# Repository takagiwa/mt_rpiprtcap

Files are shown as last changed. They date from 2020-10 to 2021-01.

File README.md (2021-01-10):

# mt_rpiprtcap

Capture print data via parallel port on PC and some measurement equipments.

Main purpose is for taking hardcopy on elder measurement equipments that don't have USB or modern hardcopy device.

The PCB design file for KiCAD is in "board" directory.

The software code depends on pigpiod is in "software_rpi" directory.

you can build software as following (comes from pigpio)

gcc -Wall -pthread -o prt prt.cpp -lpigpiod_if2 -lrt

I have tested on Raspbian GNU/Linux 10 (buster), gcc 8.3.0, pigpio 78 (get_pigpio_version reported) and Raspberry Pi 4B 2GB.

The software still have some huge bugs.

* failed to capture first byte
* sometime failed to capture data (3 or 4 characters in 10MB).
* too slow (almost 1KB/sec)

There are no interpreters that convert from parallel port data to picture yet.

How to use

connect all devices.

power-on all devices.

start software_rpi/prt executable

start print on PC or equipment

when it seems ended, Ctrl-C on prt executable

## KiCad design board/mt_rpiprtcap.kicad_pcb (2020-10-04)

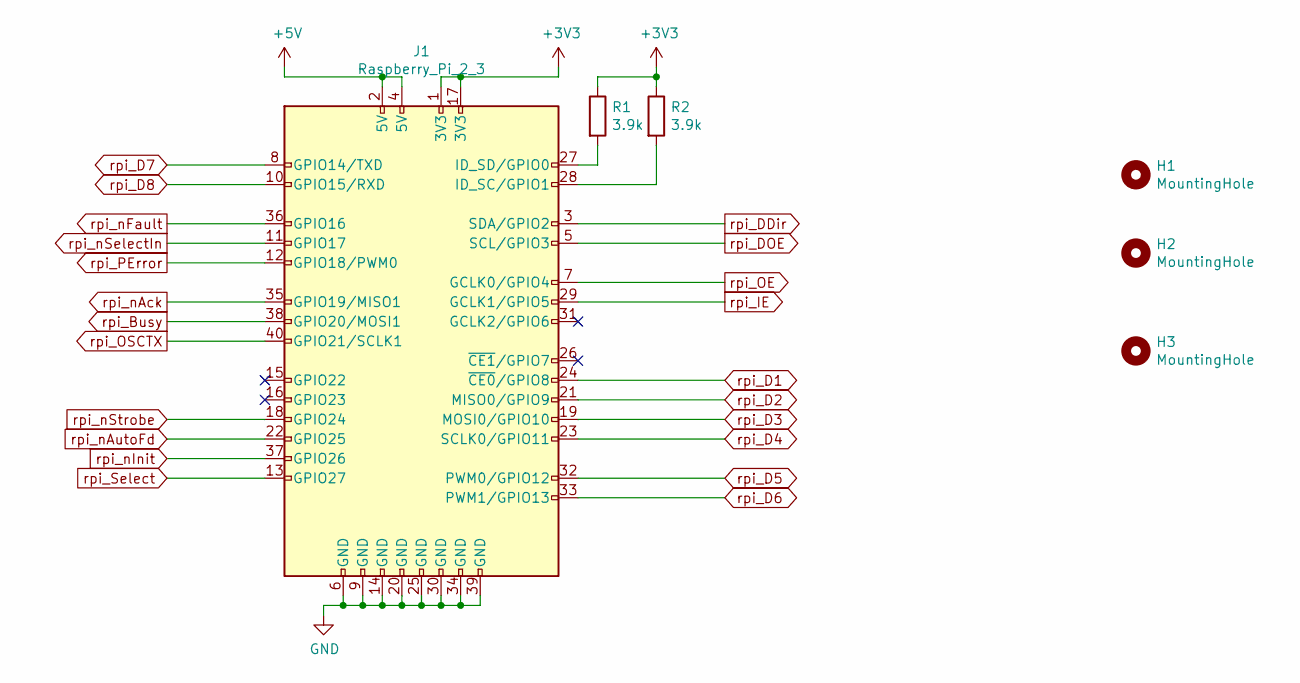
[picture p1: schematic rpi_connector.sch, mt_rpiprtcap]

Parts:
H1, H2, H3: MountingHole; MountingHole_2.7mm_M2.5
J1: Raspberry_Pi_2_3; Pin_Header_Straight_2x20_Pitch2.54mm
R1, R2: 3.9k; R_0805_HandSoldering

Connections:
+3V3: J1.1 (3V3), J1.17 (3V3), R1.1, R2.1; also elsewhere on the board
+5V: J1.2 (5V), J1.4 (5V); also elsewhere on the board
GND: J1.6 (GND), J1.9 (GND), J1.14 (GND), J1.20 (GND), J1.25 (GND), J1.30 (GND), J1.34 (GND), J1.39 (GND); also elsewhere on the board
unnamed: J1.27 (ID_SD/GPIO0), R1.2
unnamed: J1.28 (ID_SC/GPIO1), R2.2
rpi_Busy: J1.38 (GPIO20/MOSI1); also elsewhere on the board
rpi_D1: J1.24 (~CE0~/GPIO8); also elsewhere on the board
rpi_D2: J1.21 (MISO0/GPIO9); also elsewhere on the board
rpi_D3: J1.19 (MOSI0/GPIO10); also elsewhere on the board
rpi_D4: J1.23 (SCLK0/GPIO11); also elsewhere on the board
rpi_D5: J1.32 (PWM0/GPIO12); also elsewhere on the board
rpi_D6: J1.33 (PWM1/GPIO13); also elsewhere on the board
rpi_D7: J1.8 (GPIO14/TXD); also elsewhere on the board
rpi_D8: J1.10 (GPIO15/RXD); also elsewhere on the board
rpi_DDir: J1.3 (SDA/GPIO2); also elsewhere on the board
rpi_DOE: J1.5 (SCL/GPIO3); also elsewhere on the board
rpi_IE: J1.29 (GCLK1/GPIO5); also elsewhere on the board
rpi_OE: J1.7 (GCLK0/GPIO4); also elsewhere on the board
rpi_OSCTX: J1.40 (GPIO21/SCLK1); also elsewhere on the board
rpi_PError: J1.12 (GPIO18/PWM0); also elsewhere on the board
rpi_Select: J1.13 (GPIO27); also elsewhere on the board
rpi_nAck: J1.35 (GPIO19/MISO1); also elsewhere on the board
rpi_nAutoFd: J1.22 (GPIO25); also elsewhere on the board
rpi_nFault: J1.36 (GPIO16); also elsewhere on the board
rpi_nInit: J1.37 (GPIO26); also elsewhere on the board
rpi_nSelectIn: J1.11 (GPIO17); also elsewhere on the board
rpi_nStrobe: J1.18 (GPIO24); also elsewhere on the board

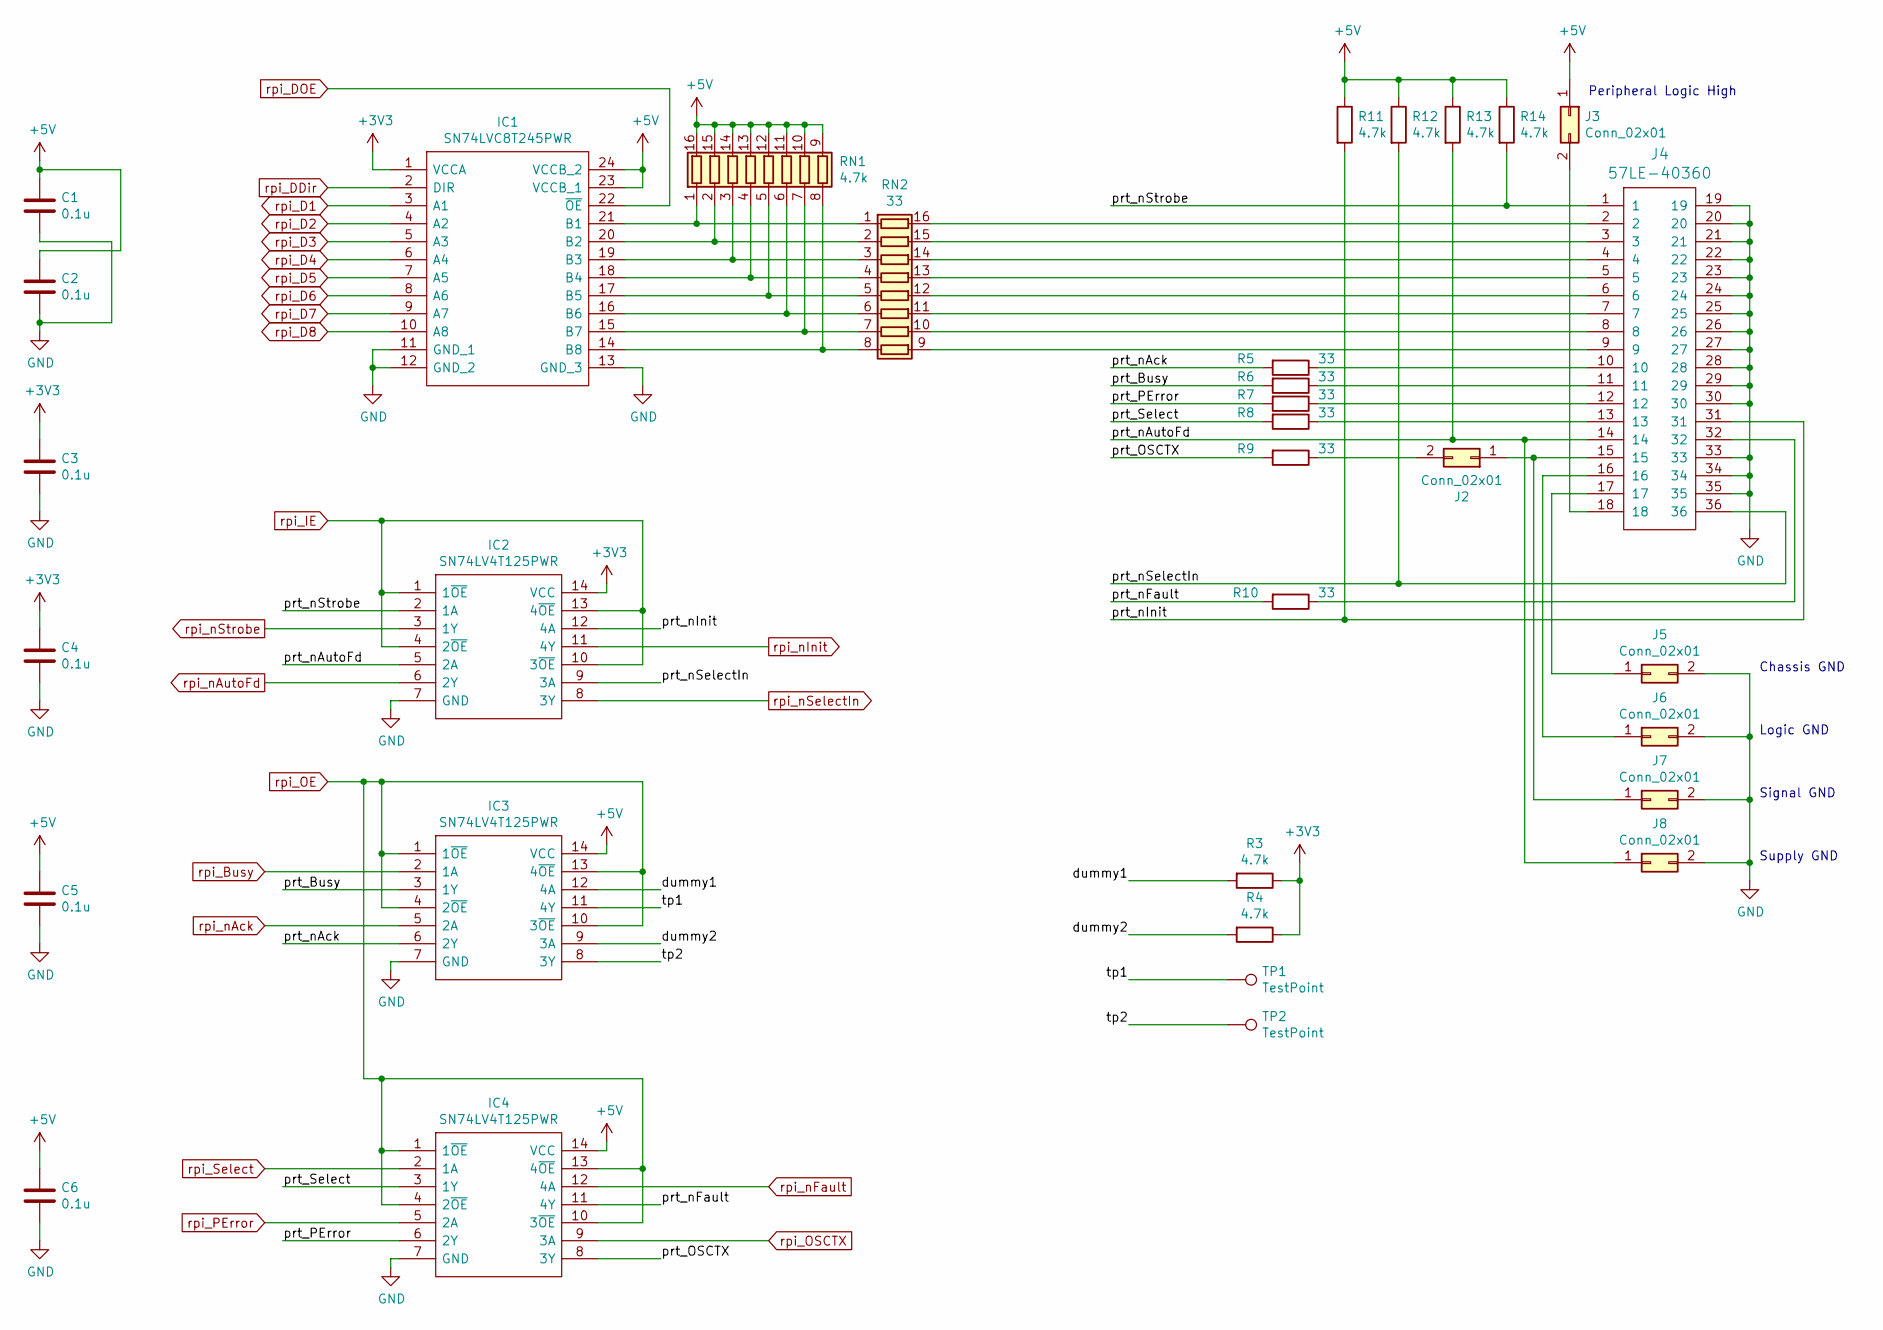
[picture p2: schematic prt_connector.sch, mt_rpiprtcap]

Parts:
C1, C2, C3, C4, C5, C6: 0.1u; C_0805_HandSoldering
IC1: SN74LVC8T245PWR; SOP65P640X120-24N; Mouser Part Number 595-SN74LVC8T245PWR
IC2, IC3, IC4: SN74LV4T125PWR; SOP65P640X120-14N; Mouser Part Number 595-SN74LV4T125PWR
J2, J3, J5, J6, J7, J8: Conn_02x01; Pin_Header_Straight_2x01_Pitch2.54mm
J4: 57LE-40360
R3, R4, R11, R12, R13, R14: 4.7k; R_0805_HandSoldering
R5, R6, R7, R8, R9, R10: 33; R_0805_HandSoldering
RN1: 4.7k; R_Array_Convex_8x0602
RN2: 33; R_Array_Convex_8x0602
TP1, TP2: TestPoint; Measurement_Point_Round-SMD-Pad_Small

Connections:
+3V3: C3.1, C4.1, IC1.1 (VCCA), IC2.14 (VCC), R3.1, R4.1; also elsewhere on the board
+5V: C1.1, C2.1, C5.1, C6.1, IC1.23 (VCCB_1), IC1.24 (VCCB_2), IC3.14 (VCC), IC4.14 (VCC), J3.1, R11.1, R12.1, R13.1, R14.1, RN1.9 (R8.2), RN1.10 (R7.2), RN1.11 (R6.2), RN1.12 (R5.2), RN1.13 (R4.2), RN1.14 (R3.2), RN1.15 (R2.2), RN1.16 (R1.2); also elsewhere on the board
/prt_connector/dummy1: IC3.12 (4A), R3.2
/prt_connector/dummy2: IC3.9 (3A), R4.2
/prt_connector/prt_Busy: IC3.3 (1Y), R6.2
/prt_connector/prt_OSCTX: IC4.8 (3Y), R9.2
/prt_connector/prt_PError: IC4.6 (2Y), R7.2
/prt_connector/prt_Select: IC4.3 (1Y), R8.2
/prt_connector/prt_nAck: IC3.6 (2Y), R5.2
/prt_connector/prt_nAutoFd: IC2.5 (2A), J4.14, J8.1, R13.2
/prt_connector/prt_nFault: IC4.11 (4Y), R10.2
/prt_connector/prt_nInit: IC2.12 (4A), J4.31, R11.2
/prt_connector/prt_nSelectIn: IC2.9 (3A), J4.36, R12.2
/prt_connector/prt_nStrobe: IC2.2 (1A), J4.1, R14.2
/prt_connector/tp1: IC3.11 (4Y), TP1.1
/prt_connector/tp2: IC3.8 (3Y), TP2.1
GND: C1.2, C2.2, C3.2, C4.2, C5.2, C6.2, IC1.11 (GND_1), IC1.12 (GND_2), IC1.13 (GND_3), IC2.7 (GND), IC3.7 (GND), IC4.7 (GND), J4.19, J4.20, J4.21, J4.22, J4.23, J4.24, J4.25, J4.26, J4.27, J4.28, J4.29, J4.30, J4.33, J4.34, J4.35, J5.2, J6.2, J7.2, J8.2; also elsewhere on the board
unnamed: IC1.14 (B8), RN1.8 (R8.1), RN2.8 (R8.1)
unnamed: IC1.15 (B7), RN1.7 (R7.1), RN2.7 (R7.1)
unnamed: IC1.16 (B6), RN1.6 (R6.1), RN2.6 (R6.1)
unnamed: IC1.17 (B5), RN1.5 (R5.1), RN2.5 (R5.1)
unnamed: IC1.18 (B4), RN1.4 (R4.1), RN2.4 (R4.1)
unnamed: IC1.19 (B3), RN1.3 (R3.1), RN2.3 (R3.1)
unnamed: IC1.20 (B2), RN1.2 (R2.1), RN2.2 (R2.1)
unnamed: IC1.21 (B1), RN1.1 (R1.1), RN2.1 (R1.1)
unnamed: J2.1, J4.15, J7.1
unnamed: J2.2, R9.1
unnamed: J3.2, J4.18
unnamed: J4.2, RN2.16 (R1.2)
unnamed: J4.3, RN2.15 (R2.2)
unnamed: J4.4, RN2.14 (R3.2)
unnamed: J4.5, RN2.13 (R4.2)
unnamed: J4.6, RN2.12 (R5.2)
unnamed: J4.7, RN2.11 (R6.2)
unnamed: J4.8, RN2.10 (R7.2)
unnamed: J4.9, RN2.9 (R8.2)
unnamed: J4.10, R5.1
unnamed: J4.11, R6.1
unnamed: J4.12, R7.1
unnamed: J4.13, R8.1
unnamed: J4.16, J6.1
unnamed: J4.17, J5.1
unnamed: J4.32, R10.1
rpi_Busy: IC3.2 (1A); also elsewhere on the board
rpi_D1: IC1.3 (A1); also elsewhere on the board
rpi_D2: IC1.4 (A2); also elsewhere on the board
rpi_D3: IC1.5 (A3); also elsewhere on the board
rpi_D4: IC1.6 (A4); also elsewhere on the board
rpi_D5: IC1.7 (A5); also elsewhere on the board
rpi_D6: IC1.8 (A6); also elsewhere on the board
rpi_D7: IC1.9 (A7); also elsewhere on the board
rpi_D8: IC1.10 (A8); also elsewhere on the board
rpi_DDir: IC1.2 (DIR); also elsewhere on the board
rpi_DOE: IC1.22 (~OE); also elsewhere on the board
rpi_IE: IC2.1 (1~OE), IC2.4 (2~OE), IC2.10 (3~OE), IC2.13 (4~OE); also elsewhere on the board
rpi_OE: IC3.1 (1~OE), IC3.4 (2~OE), IC3.10 (3~OE), IC3.13 (4~OE), IC4.1 (1~OE), IC4.4 (2~OE), IC4.10 (3~OE), IC4.13 (4~OE); also elsewhere on the board
rpi_OSCTX: IC4.9 (3A); also elsewhere on the board
rpi_PError: IC4.5 (2A); also elsewhere on the board
rpi_Select: IC4.2 (1A); also elsewhere on the board
rpi_nAck: IC3.5 (2A); also elsewhere on the board
rpi_nAutoFd: IC2.6 (2Y); also elsewhere on the board
rpi_nFault: IC4.12 (4A); also elsewhere on the board
rpi_nInit: IC2.11 (4Y); also elsewhere on the board
rpi_nSelectIn: IC2.8 (3Y); also elsewhere on the board
rpi_nStrobe: IC2.3 (1Y); also elsewhere on the board

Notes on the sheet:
Peripheral Logic High
Chassis GND
Logic GND
Signal GND
Supply GND

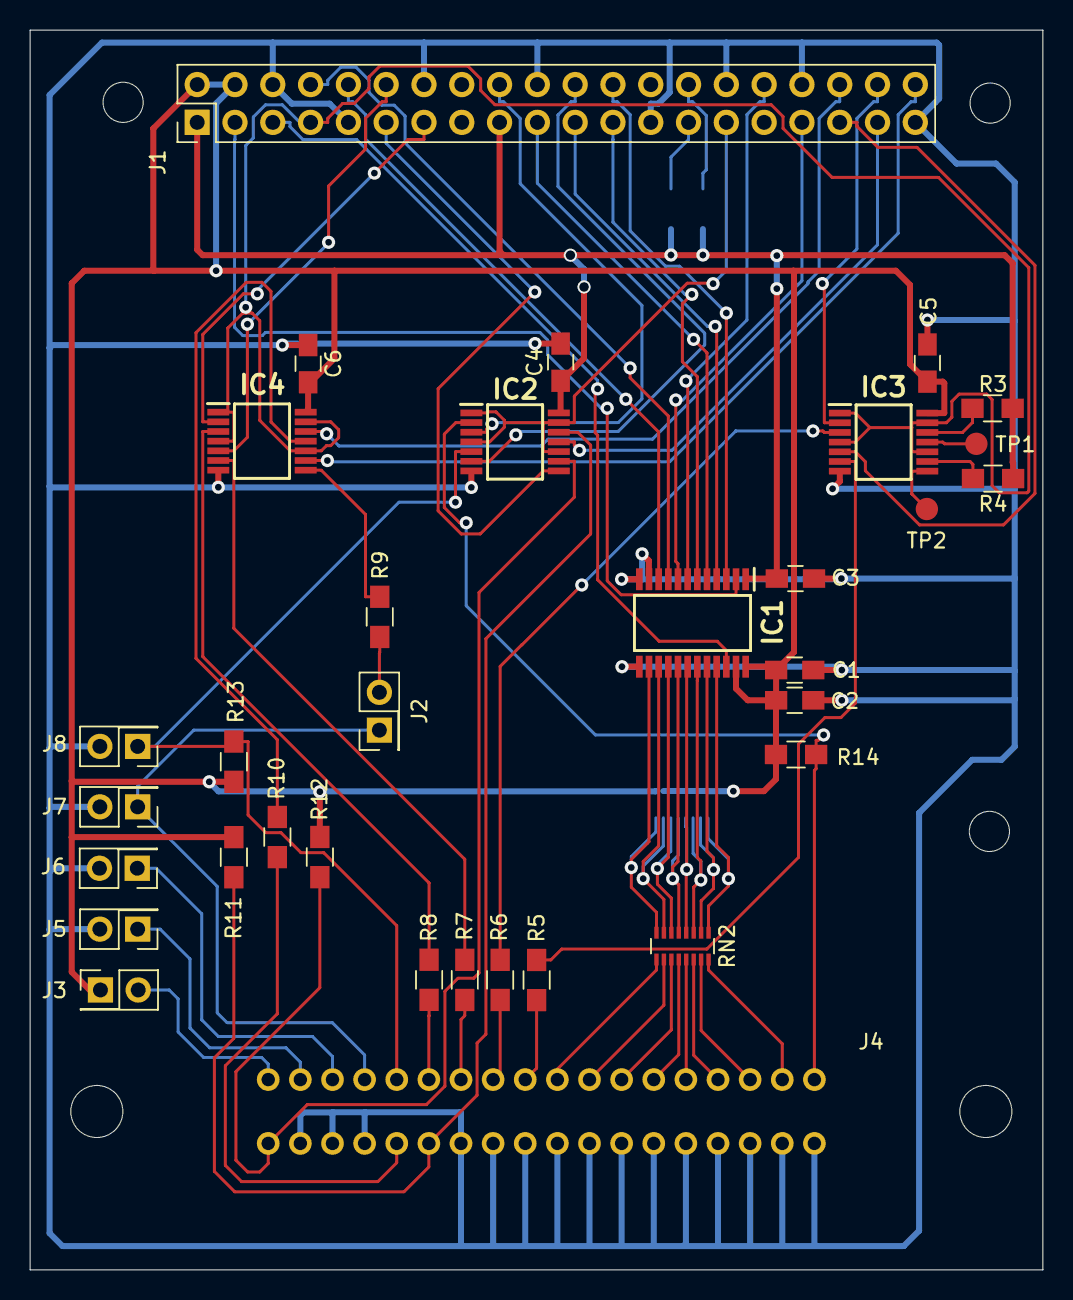
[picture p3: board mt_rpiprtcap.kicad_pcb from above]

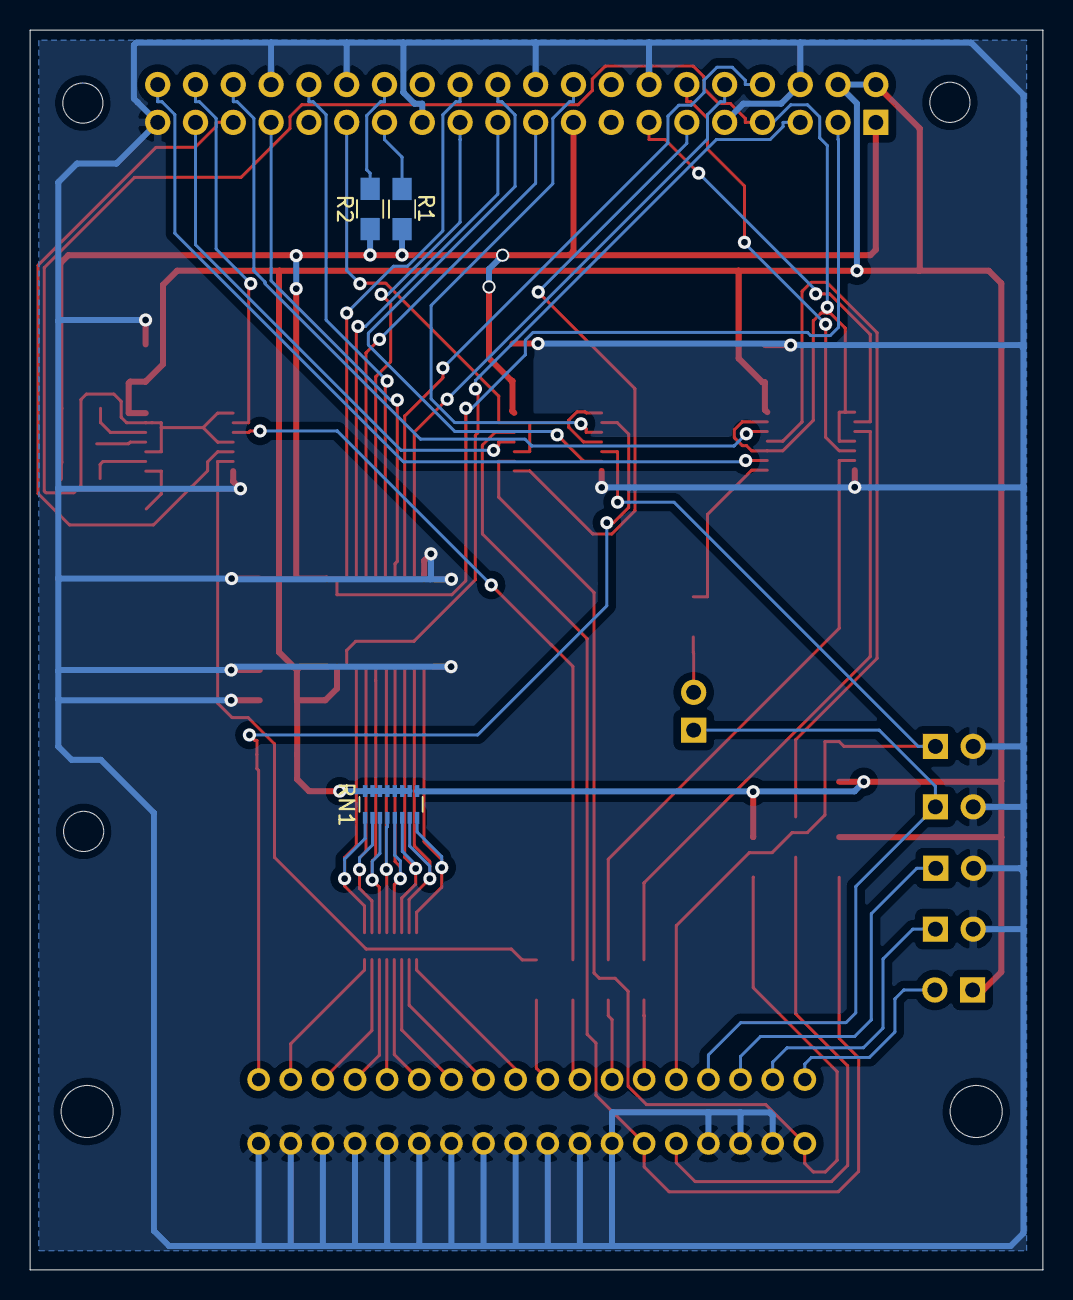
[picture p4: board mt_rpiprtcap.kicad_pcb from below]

Board: 2 copper layers, 68.1 x 83.3 mm, 39 parts (3 on the bottom side), 67 nets.

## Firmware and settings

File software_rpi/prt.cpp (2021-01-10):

#include <stdio.h>
#include <stdlib.h>
#include <string.h>
#include <time.h>
#include <signal.h>
#include <pigpiod_if2.h>

enum PRT_PORTS {
  PRT_O_DDir = 2,
  PRT_O_DOE,
  PRT_O_OE,
  PRT_O_IE,
  PRT_I_D1 = 8,
  PRT_I_D2,
  PRT_I_D3,
  PRT_I_D4,
  PRT_I_D5,
  PRT_I_D6,
  PRT_I_D7,
  PRT_I_D8,
  PRT_O_nFault,
  PRT_O_nSelectIn,
  PRT_O_PError,
  PRT_O_nAck,
  PRT_O_Busy,
  PRT_O_OSCTX,
  PRT_I_nStrobe = 24,
  PRT_I_nAutoFd,
  PRT_I_nInit,
  PRT_I_Select
};

/* Handle Ctrl-C */
/* https://qiita.com/supaiku2452/items/10772cbd2706dede06b9 */
void abrt_handler(int sig, siginfo_t *info, void *ctx);
volatile sig_atomic_t eflag = 0;

int my_set_mode(int pi, unsigned int gpio, unsigned int mode)
{
  int ret;
  ret = set_mode(pi, gpio, mode);
  if (ret < 0) {
    printf("[ERROR] set_mode error for %d: %s\n", gpio, pigpio_error(ret));
    return -1;
  }
  return 0;
}

int my_gpio_write(int pi, unsigned int gpio, unsigned level)
{
  int ret;
  ret = gpio_write(pi, gpio, level);
  if (ret < 0) {
    printf("[ERROR] gpio_write error for %d: %s\n", gpio, pigpio_error(ret));
    return -1;
  }
  return 0;
}

int main(void)
{
  unsigned int v;
  int pi;
  uint32_t r;
  int ret;
  unsigned int rd;
  int i, j, b, prev_b;
  FILE *fp;

  /* handle Ctrl-C */
  struct sigaction sa_sigabrt;
  memset(&sa_sigabrt, 0, sizeof(sa_sigabrt));
  sa_sigabrt.sa_sigaction = abrt_handler;
  sa_sigabrt.sa_flags = SA_SIGINFO;
  if ( sigaction(SIGINT, &sa_sigabrt, NULL) < 0 ) {
    exit(1);
  }

  v = pigpiod_if_version();
  printf("[INFO] pigpiod_if2 version: %d\n", v);

  pi = pigpio_start(0, 0);
  if (pi < 0) {
    printf("[ERROR] pigpio_start() failed: %s\n", pigpio_error(pi));
    return -1;
  }
  printf("[INFO] pi: %d\n", pi);

  r = get_pigpio_version(pi);
  printf("[INFO] pigpio version: %d\n", r);

  r = get_hardware_revision(pi);
  printf("[INFO] hardware revision: %d\n", r);

  /* set initial output data */
  ret = 0;
  ret += my_gpio_write(pi, PRT_O_DDir, 0); /* input */
  ret += my_gpio_write(pi, PRT_O_DOE, 0); /* active */
  ret += my_gpio_write(pi, PRT_O_OE, 0); /* active */
  ret += my_gpio_write(pi, PRT_O_IE, 0); /* active */
  ret += my_gpio_write(pi, PRT_O_nFault, 1); /* low when error */
  ret += my_gpio_write(pi, PRT_O_nSelectIn, 1); /* high when selected and ready */
  ret += my_gpio_write(pi, PRT_O_PError, 0); /* high to "empty" */
  ret += my_gpio_write(pi, PRT_O_nAck, 1); /* low when ack */
  ret += my_gpio_write(pi, PRT_O_Busy, 0); /* high when not ready to receive */
  ret += my_gpio_write(pi, PRT_O_OSCTX, 0); /* should not used */
  if (ret != 0) {
    printf("[ERROR] initial gpio_write error.\n");
    pigpio_stop(pi);
    return -1;
  }

  /* direction setup */
  ret = 0;
  if (0) ret += my_set_mode(pi, 0, PI_INPUT);  /* pullup */
  if (0) ret += my_set_mode(pi, 1, PI_INPUT);  /* pullup */
  ret += my_set_mode(pi, 2, PI_OUTPUT); /* DDir */
  ret += my_set_mode(pi, 3, PI_OUTPUT); /* DOE */
  ret += my_set_mode(pi, 4, PI_OUTPUT); /* OE */
  ret += my_set_mode(pi, 5, PI_OUTPUT); /* IE */
  ret += my_set_mode(pi, 6, PI_INPUT);  /* N.C. */
  ret += my_set_mode(pi, 7, PI_INPUT);  /* N.C. */
  ret += my_set_mode(pi, 8, PI_INPUT);  /* D1 */
  ret += my_set_mode(pi, 9, PI_INPUT);  /* D2 */
  ret += my_set_mode(pi, 10, PI_INPUT); /* D3 */
  ret += my_set_mode(pi, 11, PI_INPUT); /* D4 */
  ret += my_set_mode(pi, 12, PI_INPUT); /* D5 */
  ret += my_set_mode(pi, 13, PI_INPUT); /* D6 */
  ret += my_set_mode(pi, 14, PI_INPUT); /* D7 */
  ret += my_set_mode(pi, 15, PI_INPUT); /* D8 */
  ret += my_set_mode(pi, 16, PI_OUTPUT); /* nFault */
  ret += my_set_mode(pi, 17, PI_OUTPUT); /* nSelectIn */
  ret += my_set_mode(pi, 18, PI_OUTPUT); /* PError */
  ret += my_set_mode(pi, 19, PI_OUTPUT); /* nAck */
  ret += my_set_mode(pi, 20, PI_OUTPUT); /* Busy */
  ret += my_set_mode(pi, 21, PI_OUTPUT); /* OSCTX */
  ret += my_set_mode(pi, 22, PI_INPUT); /* N.C. */
  ret += my_set_mode(pi, 23, PI_INPUT); /* N.C. */
  ret += my_set_mode(pi, 24, PI_INPUT); /* nStrobe */
  ret += my_set_mode(pi, 25, PI_INPUT); /* nAutoFd */
  ret += my_set_mode(pi, 26, PI_INPUT); /* nInit */
  ret += my_set_mode(pi, 27, PI_INPUT); /* Select */
  if (ret != 0) {
    printf("[ERROR] set_mode error.\n");
    pigpio_stop(pi);
    return -1;
  }

  ret = 0;
  ret += my_gpio_write(pi, PRT_O_DDir, 0); /* input */
  ret += my_gpio_write(pi, PRT_O_DOE, 0); /* active */
  ret += my_gpio_write(pi, PRT_O_OE, 0); /* active */
  ret += my_gpio_write(pi, PRT_O_IE, 0); /* active */
  ret += my_gpio_write(pi, PRT_O_nFault, 1); /* low when error */
  ret += my_gpio_write(pi, PRT_O_nSelectIn, 1); /* high when selected and ready */
  ret += my_gpio_write(pi, PRT_O_PError, 0); /* high to "empty" */
  ret += my_gpio_write(pi, PRT_O_nAck, 1); /* low when ack */
  ret += my_gpio_write(pi, PRT_O_Busy, 0); /* high when not ready to receive */
  ret += my_gpio_write(pi, PRT_O_OSCTX, 0); /* should not used */
  if (ret != 0) {
    printf("[ERROR] initial gpio_write error.\n");
    pigpio_stop(pi);
    return -1;
  }

  fp = fopen("prt.bin", "wb");
  if (fp == NULL) {
    printf("[ERROR] Failed to open file.\n");
    pigpio_stop(pi);
    return -1;
  }

  i = 0;
  j = 0;
  prev_b = 1;
  while (!eflag) {
    /* find falling edge of nStrobe */
    b = gpio_read(pi, PRT_I_nStrobe);
    if ((prev_b == 1) && ((b & 0x1) == 0)) {
      /* negate Busy */
      ret = my_gpio_write(pi, PRT_O_Busy, 1);

      rd = 0;
      for (i = 0; i < 8; i++) {
        rd |= (gpio_read(pi, i+PRT_I_D1) & 0x1) << i;
      }
      putc(rd, fp);

      /* assert & de-assert nAck. Also assert Busy */
      ret = my_gpio_write(pi, PRT_O_nAck, 0);
      ret = my_gpio_write(pi, PRT_O_nAck, 1);
      if (0) ret = my_gpio_write(pi, PRT_O_Busy, 0);

      j++;
    } else {
      ret = my_gpio_write(pi, PRT_O_Busy, 0);
    }
    prev_b = b;
  }

  printf("Number of bytes: %d\n", j);

  fclose(fp);
  pigpio_stop(pi);
  return 0;
}

/* Handle Ctrl-C */
void abrt_handler(int sig, siginfo_t *info, void *ctx) {
  printf("si_signo:%d\nsi_code:%d\n", info->si_signo, info->si_code);
  printf("si_pid:%d\nsi_uid:%d\n", (int)info->si_pid, (int)info->si_uid);
  eflag = 1;
}

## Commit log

2020-09-28 first proto type board
    [mt_rpiprtcap-B_Cu.gbl, mt_rpiprtcap-B_Mask.gbs, mt_rpiprtcap-B_Paste.gbp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]
2020-10-04 Update sheet information.
    [mt_rpiprtcap.kicad_pcb, mt_rpiprtcap.sch, prt_connector.sch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]

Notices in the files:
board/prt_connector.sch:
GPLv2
